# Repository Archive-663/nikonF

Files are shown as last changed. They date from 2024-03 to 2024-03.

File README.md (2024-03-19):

# Lot no. 017 | Nikon F Accessories

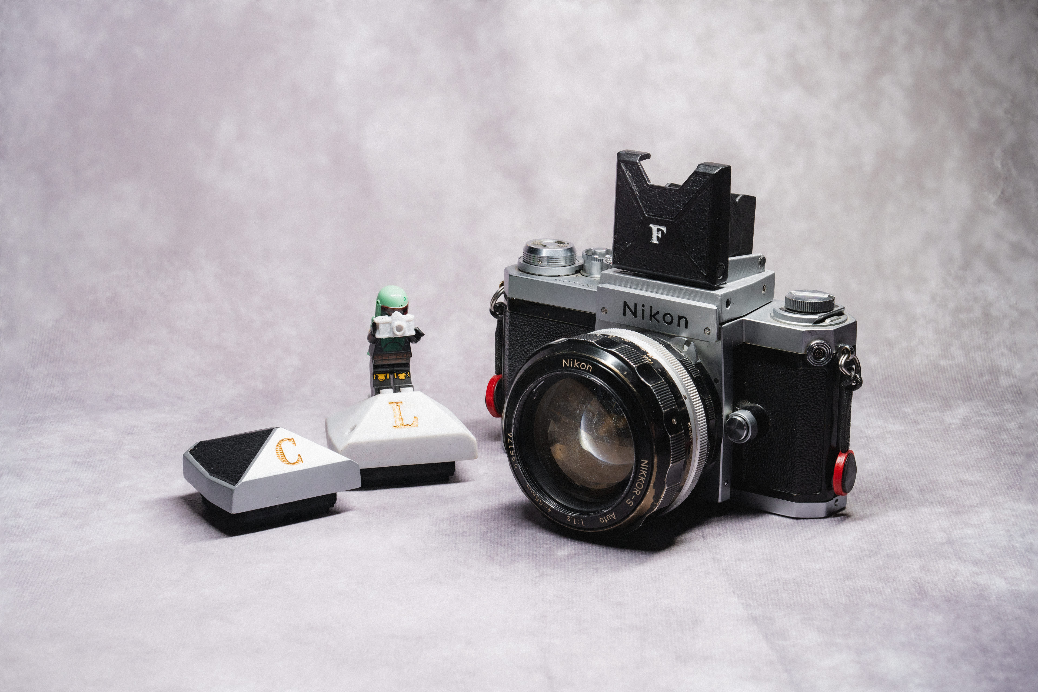
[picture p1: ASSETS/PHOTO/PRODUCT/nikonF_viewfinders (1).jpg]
productPhoto001

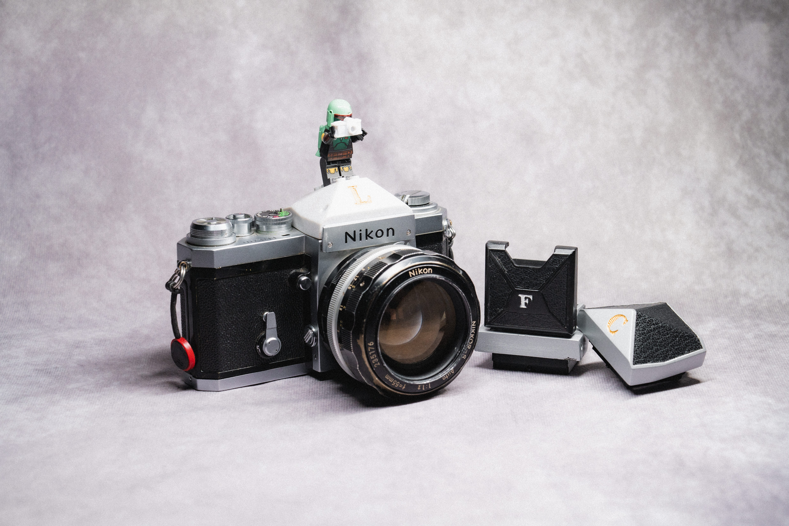
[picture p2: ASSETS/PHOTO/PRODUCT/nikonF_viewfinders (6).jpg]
productPhoto002


### In this repository:
- [Viewfinders](https://github.com/Archive-663/nikonF/tree/main/viewFinders)

### Background Story:
I picked up a Nikon F, FTN finder, and a Nikkor 55mm f1.2 to make a NASA Nikon F. While that particular project is on the backburner, I wanted to shoot the Nikon F with something that wasn't so obtrusively large. I had a broken Canon FTb and figured I could probably use the prism for a DIY viewfinder on my Nikon F. Along with the eye level finder I wanted the cool hipster waist level finder so I could be cool too. For the WLF I picked up the official WLF so I had a point of reference to build on.

There will be more accessories coming down the pipeline like an L-Bracket or Arca-Swiss compatible Grip. 

### Help support Archive 663 with a dontation or monthly sub



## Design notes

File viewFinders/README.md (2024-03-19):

# Lot no. 017 | Nikon F Viewfinders

productPhoto001
productPhoto002

### Features:
- Customizeable Eye Level Finder using whatever spare prism and prism lens you have laying around. Will need CAD software to modify the template to fit your prism combo.
- Simple Waist Level Finder.
- Minimal hardware for assembly.

### In this repository:
- [Eye Level Finder](https://github.com/Archive-663/nikonF/tree/main/viewFinders/eyeLevelFinder)
- [Waist Level Finder](https://github.com/Archive-663/nikonF/tree/main/viewFinders/waistLevelFinder)

### Accompanying video:
<a href='https://youtu.be/oAtRqYk0Bp8' target='_blank'>005 / / the one where i learn to be comfortable in the shadows</a>

### Background Story:
I picked up a Nikon F, FTN finder, and a Nikkor 55mm f1.2 to make a NASA Nikon F. While that particular project is on the backburner, I wanted to shoot the Nikon F with something that wasn't so obtrusively large. I had a broken Canon FTb and figured I could probably use the prism for a DIY viewfinder on my Nikon F. Along with the eye level finder I wanted the cool hipster waist level finder so I could be cool too. For the WLF I picked up the official WLF so I had a point of reference to build on.

The waist level finder was designed with reliability in mind. I tried multiple designs for a compact 3d printed torsion spring but couldn't figure one out with the assembly I had already. I believe having a manual operation for opening and closing the waist level finder will lead to a longer lasting Waist Level Finder. 

### Samples:
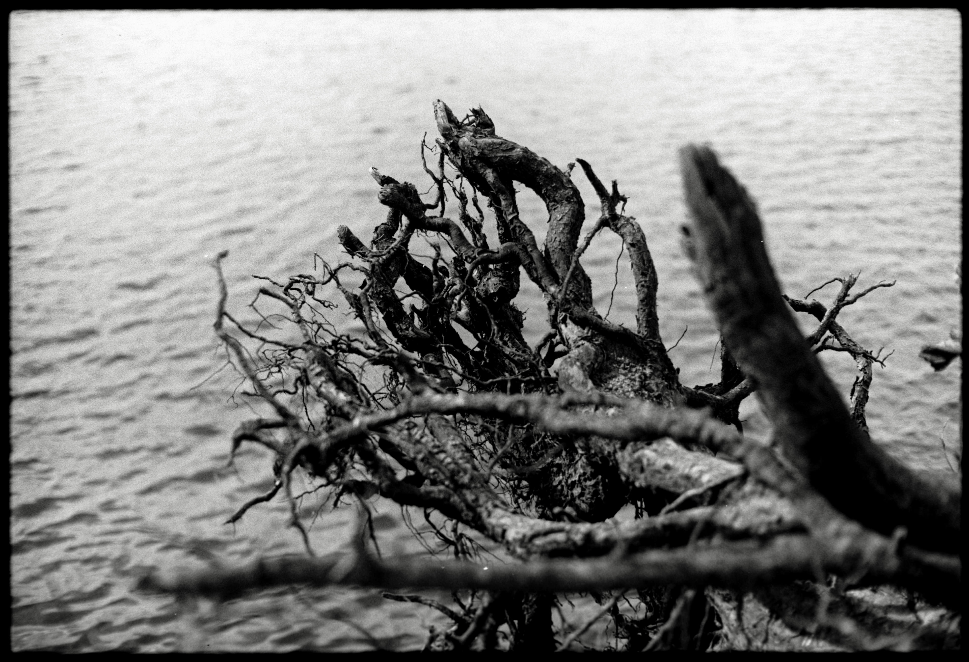
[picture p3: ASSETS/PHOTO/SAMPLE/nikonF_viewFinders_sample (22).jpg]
samplePhoto001

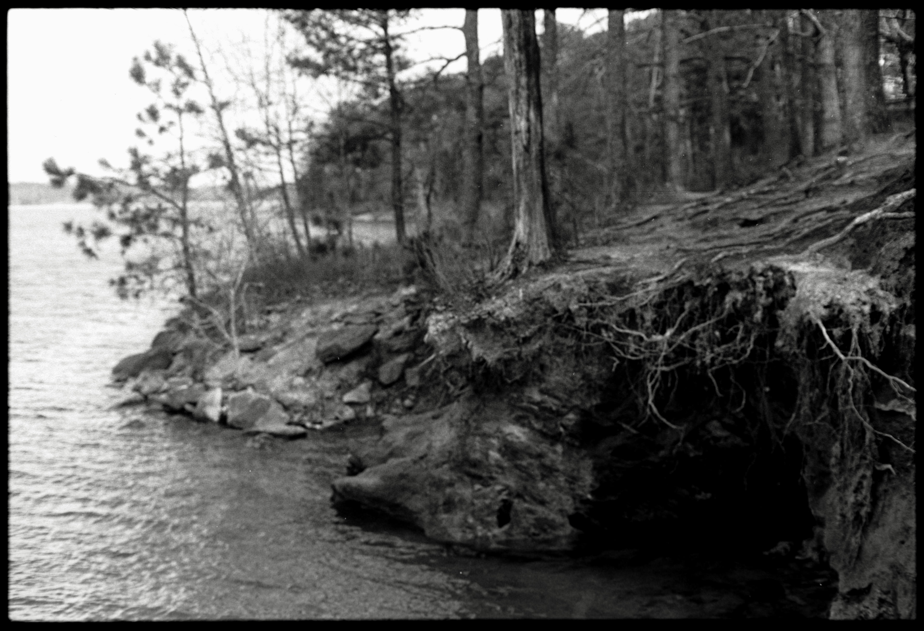
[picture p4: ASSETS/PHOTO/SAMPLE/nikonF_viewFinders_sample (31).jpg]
samplePhoto002

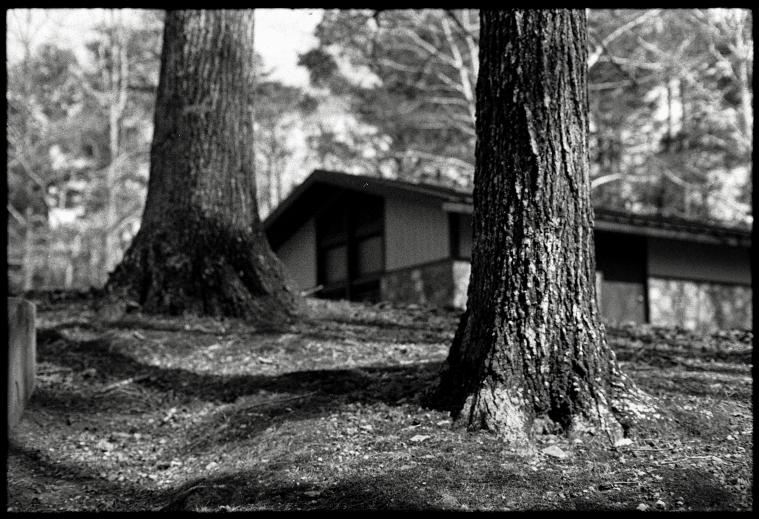
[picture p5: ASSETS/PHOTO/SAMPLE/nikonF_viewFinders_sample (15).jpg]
samplePhoto003

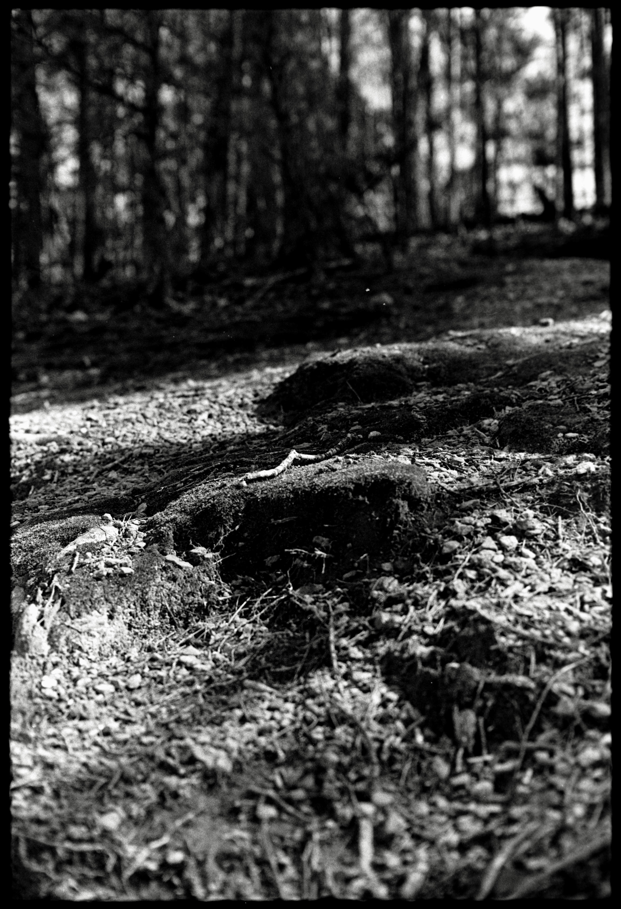
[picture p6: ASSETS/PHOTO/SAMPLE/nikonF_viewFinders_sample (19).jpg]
samplePhoto004

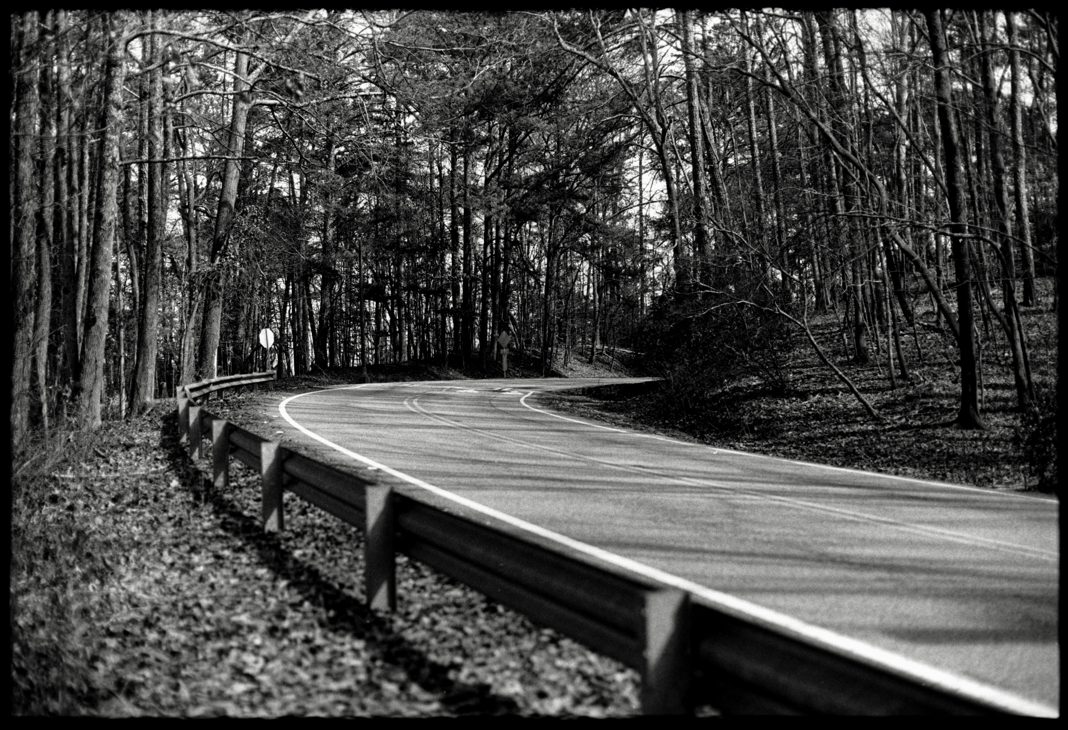
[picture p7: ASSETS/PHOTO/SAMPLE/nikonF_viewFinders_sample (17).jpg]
samplePhoto005

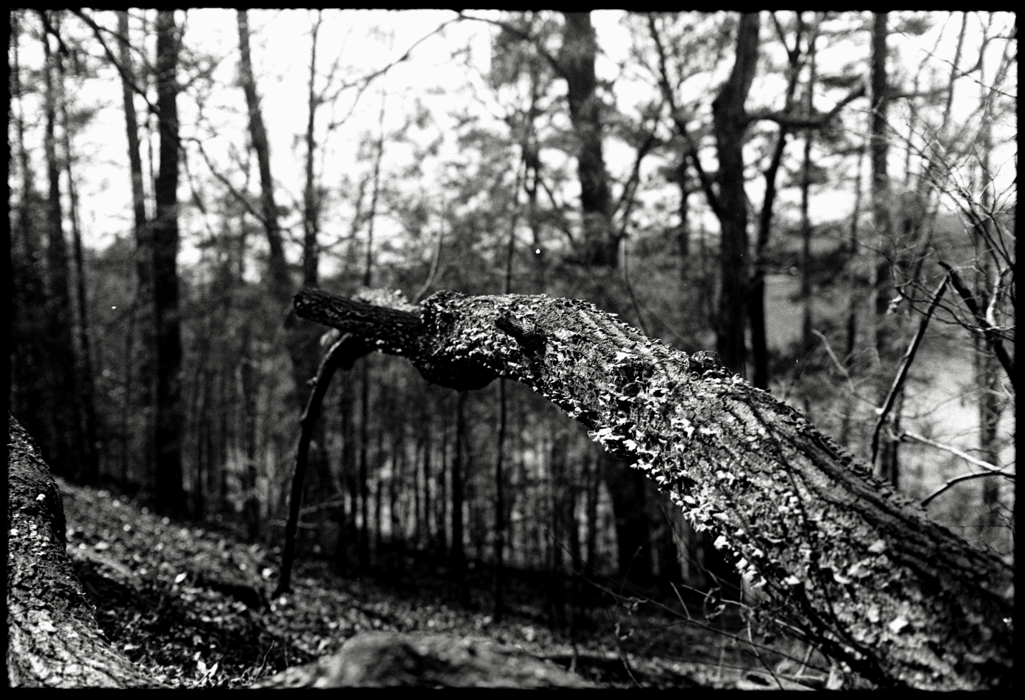
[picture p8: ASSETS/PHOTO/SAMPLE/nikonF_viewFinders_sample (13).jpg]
samplePhoto006


### Help support Archive 663 with a dontation or monthly sub



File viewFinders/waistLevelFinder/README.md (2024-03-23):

# Lot no. 017 | Nikon F Viewfinders - Waist Level Finder

productPhoto001
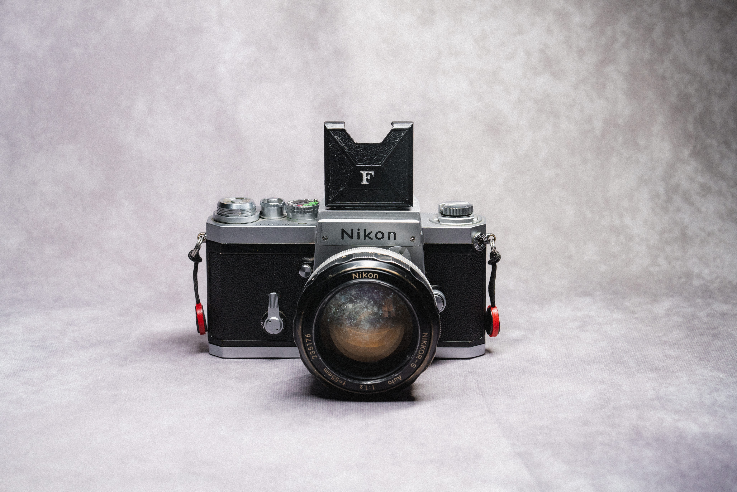
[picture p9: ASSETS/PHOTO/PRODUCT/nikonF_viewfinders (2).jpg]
productPhoto002

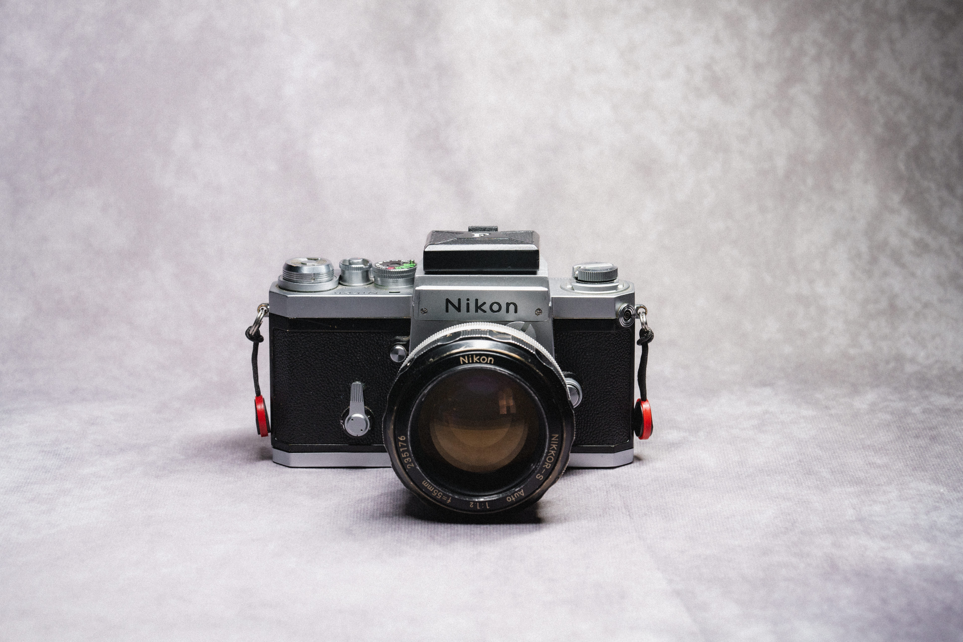
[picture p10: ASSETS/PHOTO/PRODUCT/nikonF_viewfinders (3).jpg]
productPhoto003

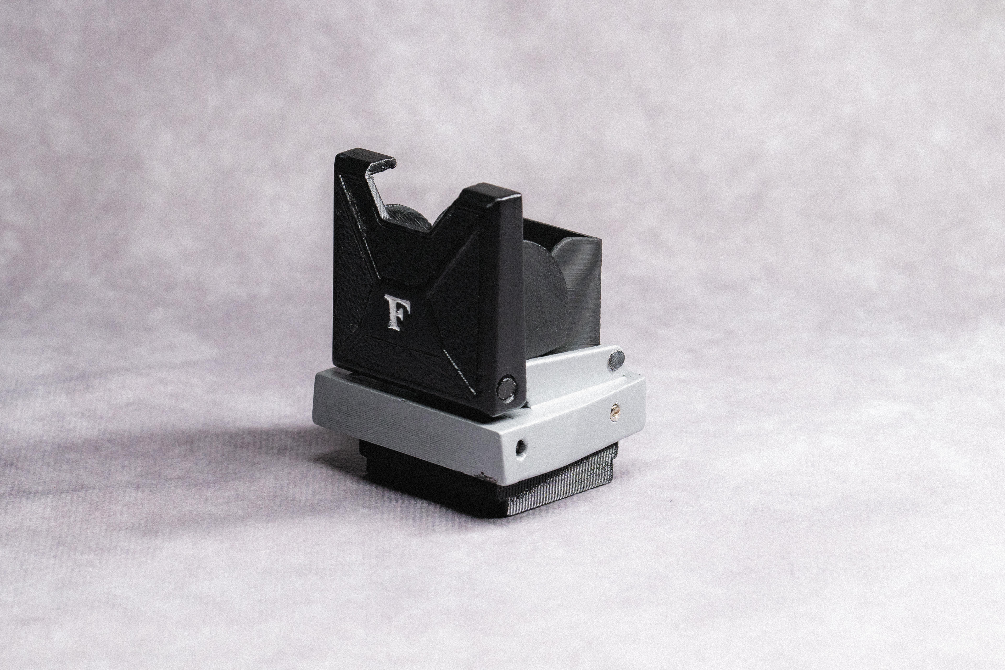
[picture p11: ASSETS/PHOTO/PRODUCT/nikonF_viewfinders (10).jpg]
productPhoto004

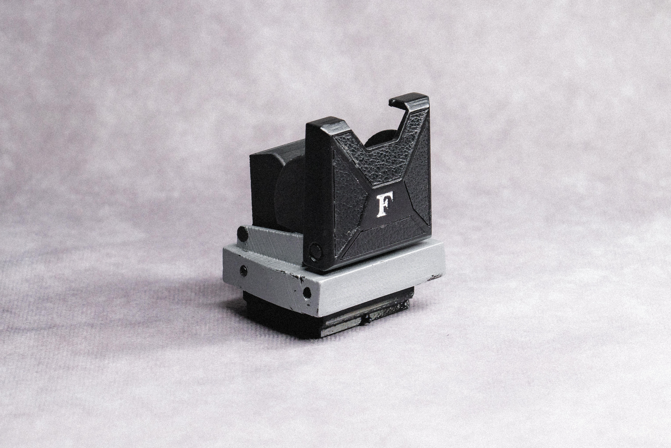
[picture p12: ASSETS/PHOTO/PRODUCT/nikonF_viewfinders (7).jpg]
productPhoto005

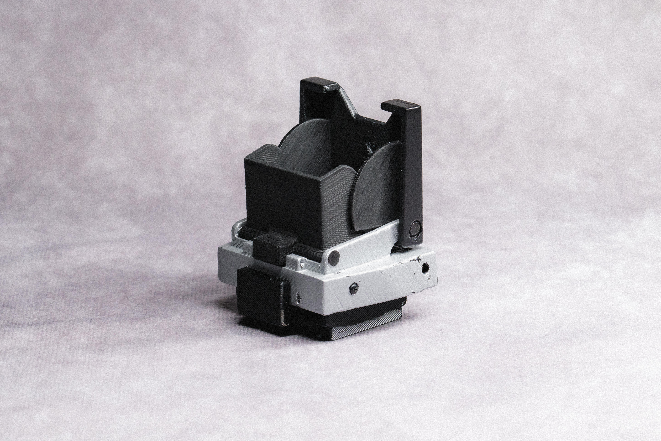
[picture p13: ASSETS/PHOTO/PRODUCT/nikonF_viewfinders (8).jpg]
productPhoto006

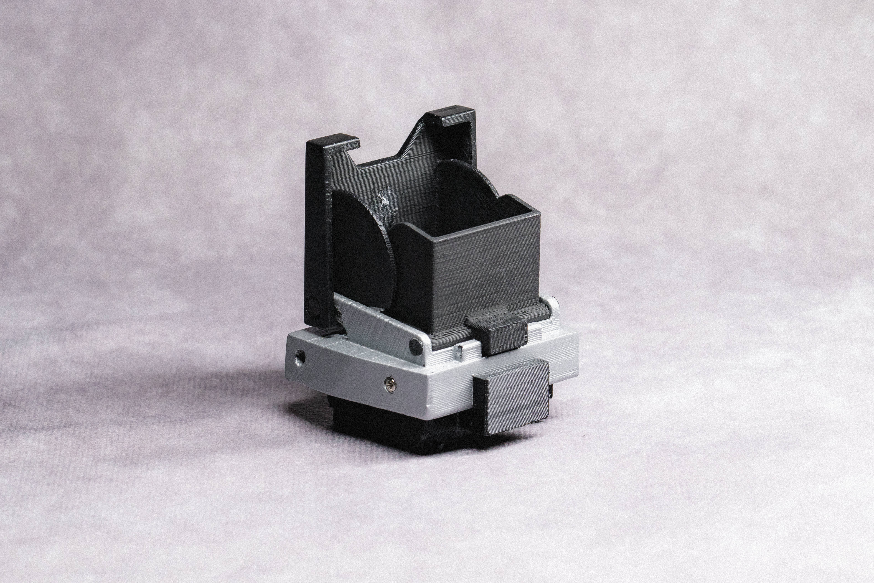
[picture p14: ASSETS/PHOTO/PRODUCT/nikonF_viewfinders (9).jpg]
productPhoto007


### What you'll need:
- 4x M1.6 x 5mm pan head screws (PETG) or self-tappin screws (ABS or PETG)
- 1x M1.6 tap
- 1x 55mm length of 1.75mm filament for upper baffle hinge
- 1x 50mm length of 1.75mm filament for lower baffle hinge
- Sheet of Leatherette

### What would be helpful:
- M1.4 drill bit
- M1.8/M2 drill bit
- Micro files

### Printing help:
Filament recommendation:
- ABS
- PETG

Generally, all my designs have chamfers on the print face of the STL. You can reference the supplied 'printOrientationFile.3mf' files for suggested print orientation.

### Assembly help:
Drill holes to their correct tap size before tapping.
- M1.6 requires M1.4 bore followed by an M1.6 tap.
- M1.8 or M2 bore for screw holes that aren't tapped.
- Bore the hinge holes with an M2 drill bit. Go slowly to keep heat generation down to a minmum. Use water to cool the bit while boring. 
- The hinges are simply lengths of filament with the ends hot riveted down. I use a lighter to set the filament on fire and a bronze punch to hot rivet the end. Do on both sides to lock the hinge in place.
- For the lower baffle you will need to file the hot riveted head down so the upper baffle will close properly. 

Test fit before assembling. Will need to file parts to allow free movement. Depending on your printer you'll have to file down the baffles for them to open and close freely

For the leatherette print the <a href="https://github.com/Archive-663/nikonF/blob/main/ASSETS/TEMPLATES" target='_blank'>leatherette cutting template file</a>. Apply contact cement to both surfaces and adhere the leatherette. 

If you need help opening and closing the waist level finder you can find <a href="https://github.com/Archive-663/nikonF/blob/main/ASSETS/TEMPLATES" target='_blank'>instructions here</a>.

To assemble correctly, please view the _assembly.stp file for help in parts orientation. If you do not have a CAD program, <a href="https://www.freecad.org/downloads.php" target="_blank">download FreeCAD</a> to view the assembly file and better understand how it should assemble. If using FreeCAD, the naming conventions should carry over and you will be able to see which lens element you need from the various smartphone lenses. (Verified in FreeCAD 0.18) If using something like Solid Edge open the file as an assembly to retain the names of the parts.

### Samples:
samplePhoto001
samplePhoto002
samplePhoto003
samplePhoto004
samplePhoto005
samplePhoto006

### Help support Archive 663 with a dontation or monthly sub



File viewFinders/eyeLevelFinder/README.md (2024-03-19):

# Lot no. 017 | Nikon F Viewfinders - Eye Level Finder

productPhoto001
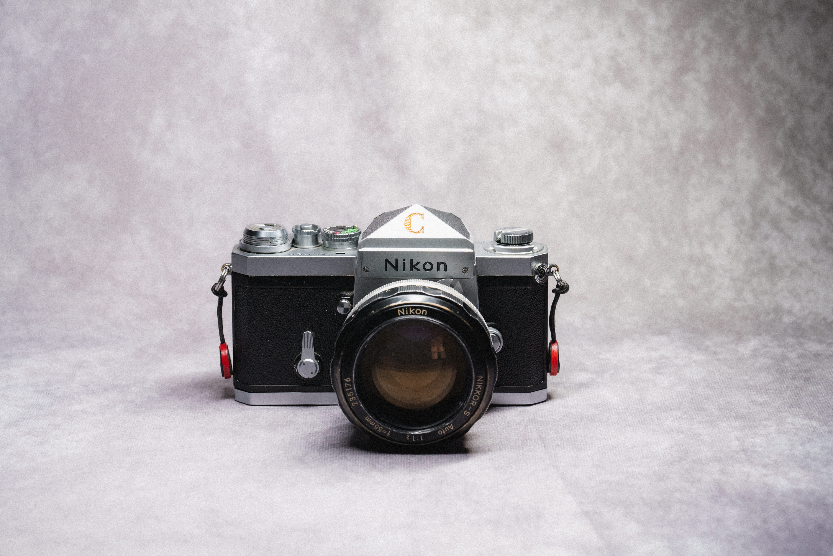
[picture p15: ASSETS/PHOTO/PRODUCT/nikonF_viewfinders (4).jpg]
productPhoto002

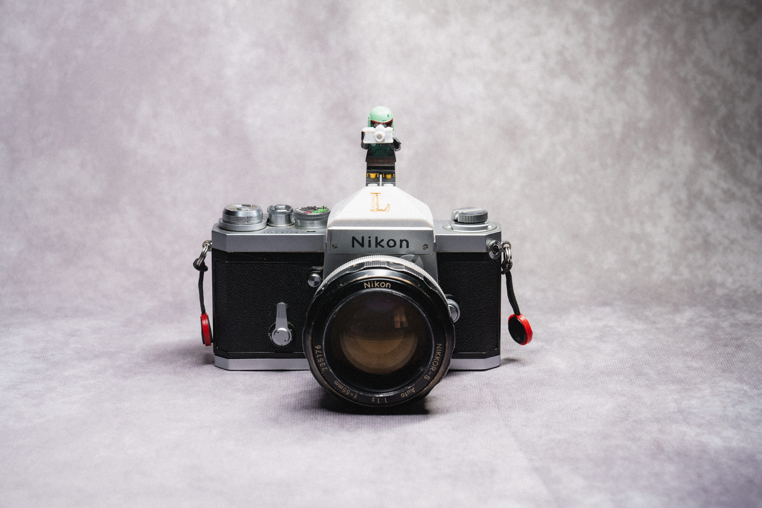
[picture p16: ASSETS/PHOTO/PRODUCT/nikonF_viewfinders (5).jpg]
productPhoto003

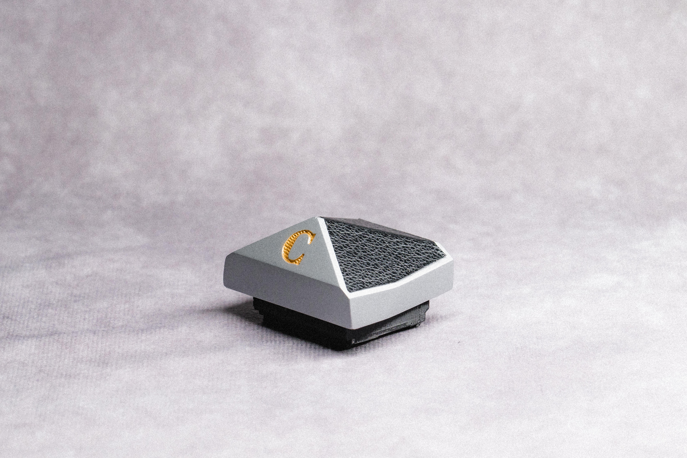
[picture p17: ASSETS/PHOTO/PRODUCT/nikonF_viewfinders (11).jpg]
productPhoto004

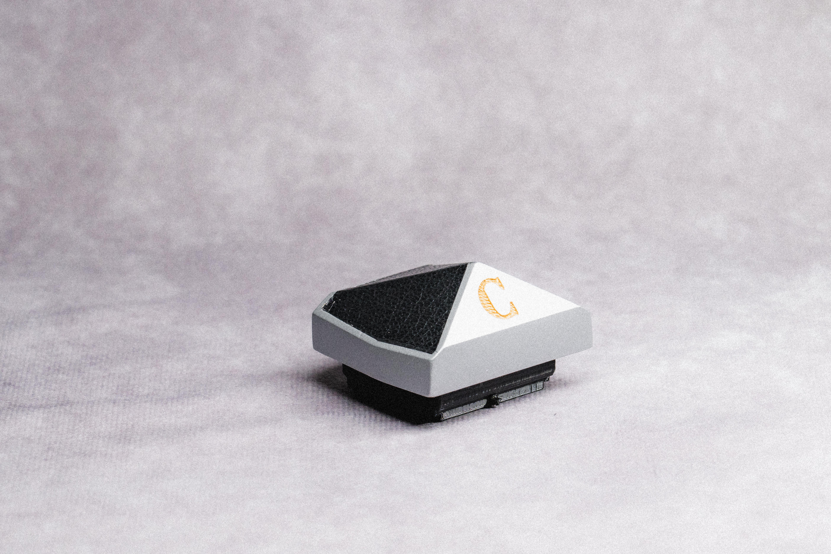
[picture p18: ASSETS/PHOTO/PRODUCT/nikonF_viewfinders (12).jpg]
productPhoto005

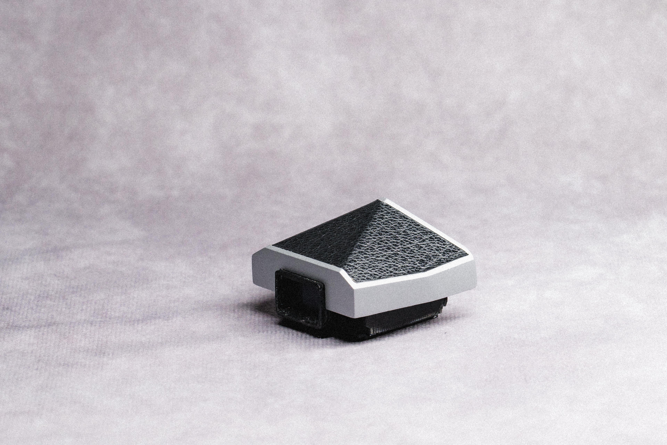
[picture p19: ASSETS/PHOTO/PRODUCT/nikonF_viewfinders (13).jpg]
productPhoto006

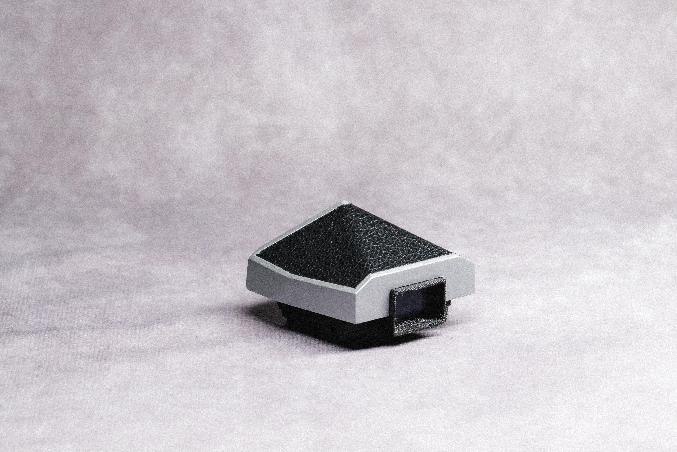
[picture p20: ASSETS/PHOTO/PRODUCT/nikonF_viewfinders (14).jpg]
productPhoto007

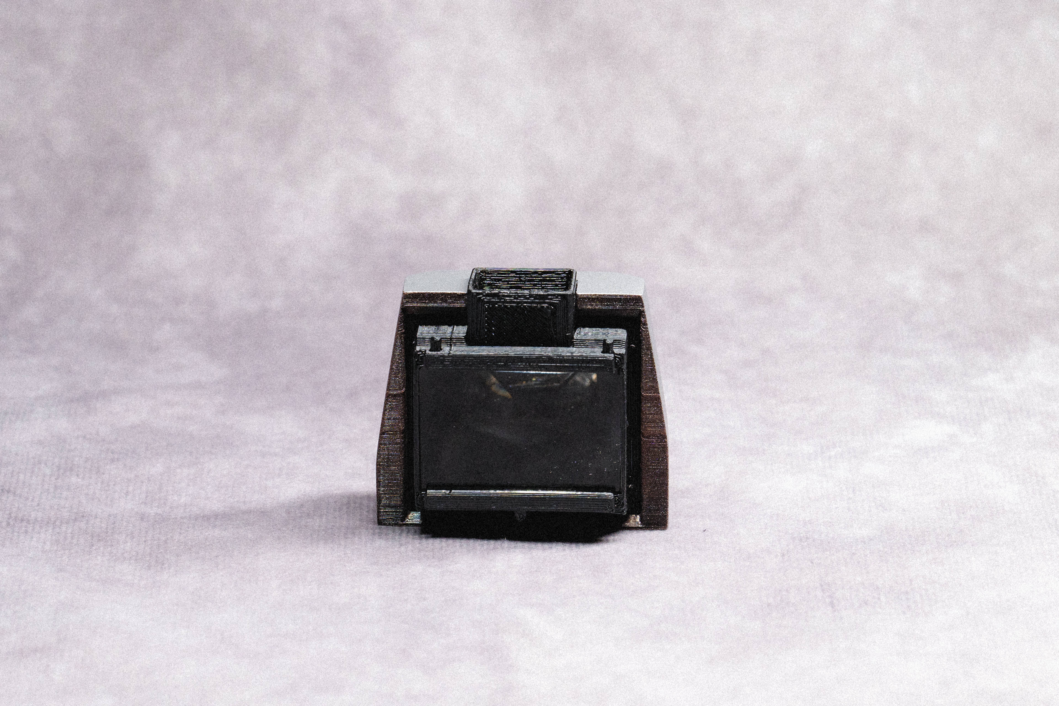
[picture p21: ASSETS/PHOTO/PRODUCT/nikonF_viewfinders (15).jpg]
productPhoto008


### What you'll need:
- 4x M1.6 x 5mm pan head screws (PETG) or self-tappin screws (ABS or PETG)
- 1x M1.6 tap
- 1x Canon FTb Prism
- 1x Canon FTb Prism Lens
  or
- 1x Prism from an SLR
- 1x Prism Lens from an SLR
- Sheet of Leatherette

### What would be helpful:
- M1.4 drill bit
- M1.8/M2 drill bit
- Micro files

### Notes:
I've included a template file so you can adjust or build your own viewfinder using a compatible prism. Additionally, there is a Lego FTB top that you can use to add some character with Legos. 

### Printing help:
Filament recommendation:
- ABS
- PETG

Generally, all my designs have chamfers on the print face of the STL. You can reference the supplied 'printOrientationFile.3mf' files for suggested print orientation.

### Assembly help:
Drill holes to their correct tap size before tapping.
- M1.6 requires M1.4 bore followed by an M1.6 tap.
- M1.8 or M2 bore for screw holes that aren't tapped.
- You'll want to handle the prism from the Canon FTB with care. Use gloves to handle to limit exposure to your body's natural oils.

Test fit before assembling. Will need to file parts to allow free movement. Depending on your printer you'll have to file down the baffles for them to open and close freely

For the leatherette print the <a href="https://github.com/Archive-663/nikonF/blob/main/ASSETS/TEMPLATES" target='_blank'>leatherette cutting template file</a>. Apply contact cement to both surfaces and adhere the leatherette. 

To assemble correctly, please view the _assembly.stp file for help in parts orientation. If you do not have a CAD program, <a href="https://www.freecad.org/downloads.php" target="_blank">download FreeCAD</a> to view the assembly file and better understand how it should assemble. If using FreeCAD, the naming conventions should carry over and you will be able to see which lens element you need from the various smartphone lenses. (Verified in FreeCAD 0.18) If using something like Solid Edge open the file as an assembly to retain the names of the parts.

### Samples:
samplePhoto001
samplePhoto002
samplePhoto003
samplePhoto004
samplePhoto005
samplePhoto006

### Help support Archive 663 with a dontation or monthly sub



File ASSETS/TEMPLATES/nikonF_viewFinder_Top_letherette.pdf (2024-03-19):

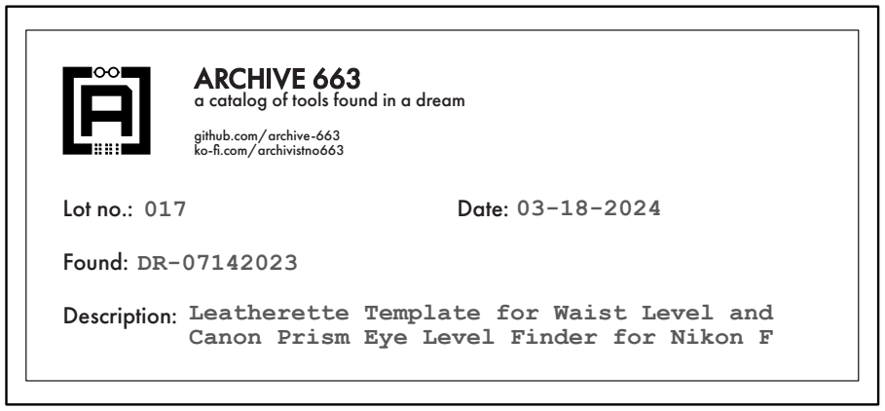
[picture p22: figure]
Lot no.:; Date:; Found:; Description:; ARCHIVE 663 a catalog of tools found in a dream; github.com/archive-663 ko-fi.com/archivistno663

Leatherette Template for Waist Level and Canon Prism Eye Level Finder for Nikon F

### Waist Level Finder

1"

### Canon Prism Eye Level Finder

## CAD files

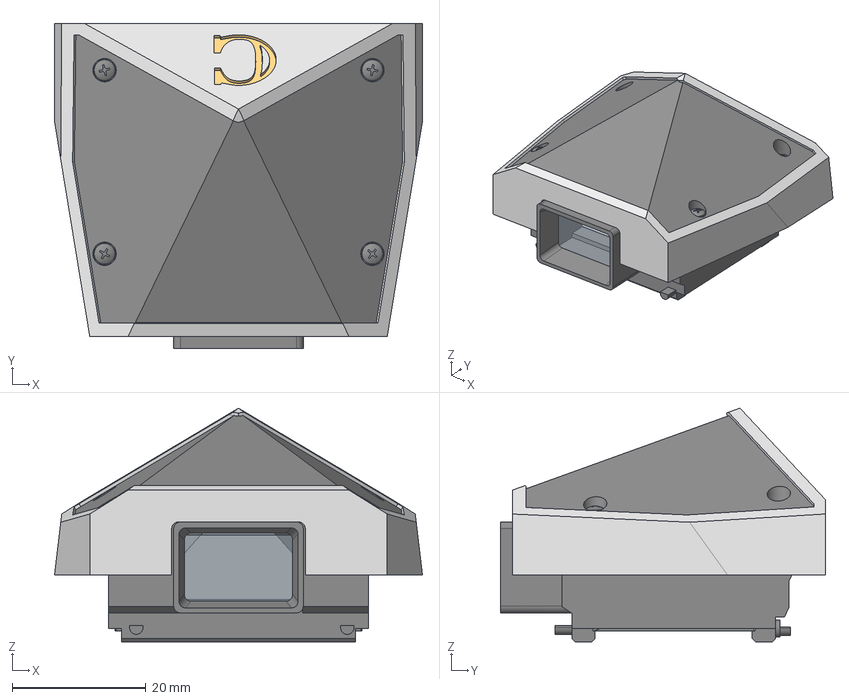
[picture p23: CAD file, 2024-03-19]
viewFinders/eyeLevelFinder/canonFTB_prism/STEP/nikonF_viewFinder_canonFTB_assembly.stp
55.1 x 48.7 x 35.0 mm
nikonF_viewFinder_canonFTBBottom
nikonF_viewFinder_canonFTBTop_STD
M1.6_panHead_5mm x 4
nikonF_prismEye_canonFTB
nikonF_prism_canonFTB

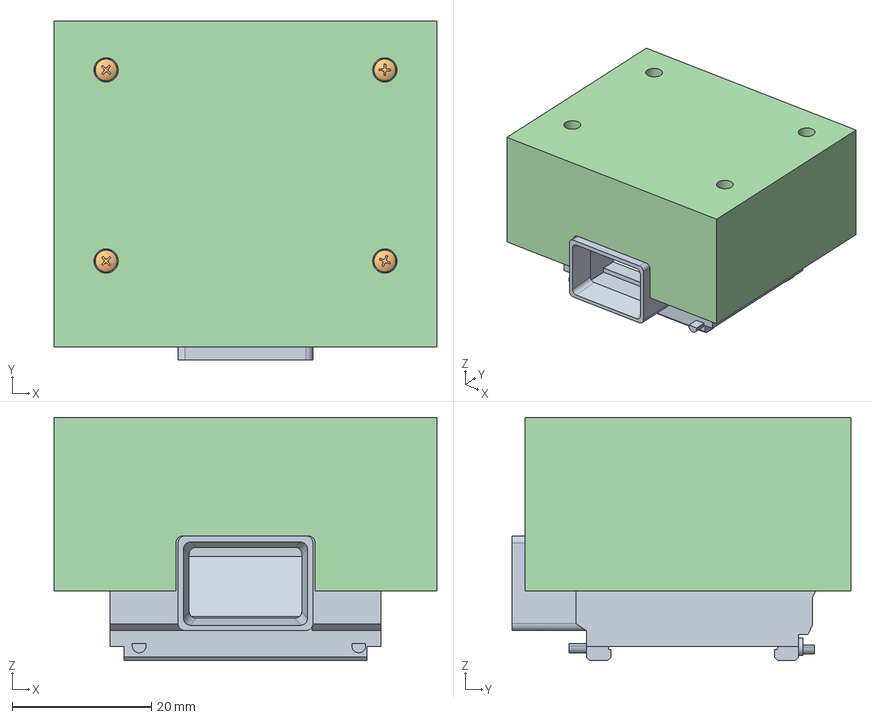
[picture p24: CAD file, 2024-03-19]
viewFinders/eyeLevelFinder/template/STEP/nikonF_viewFinder_template_assembly.stp
55.1 x 48.7 x 35.0 mm
nikonF_viewFinder_baseBottom_Template
M1.6_panHead_5mm x 4
nikonF_viewFinder_baseTop_Template

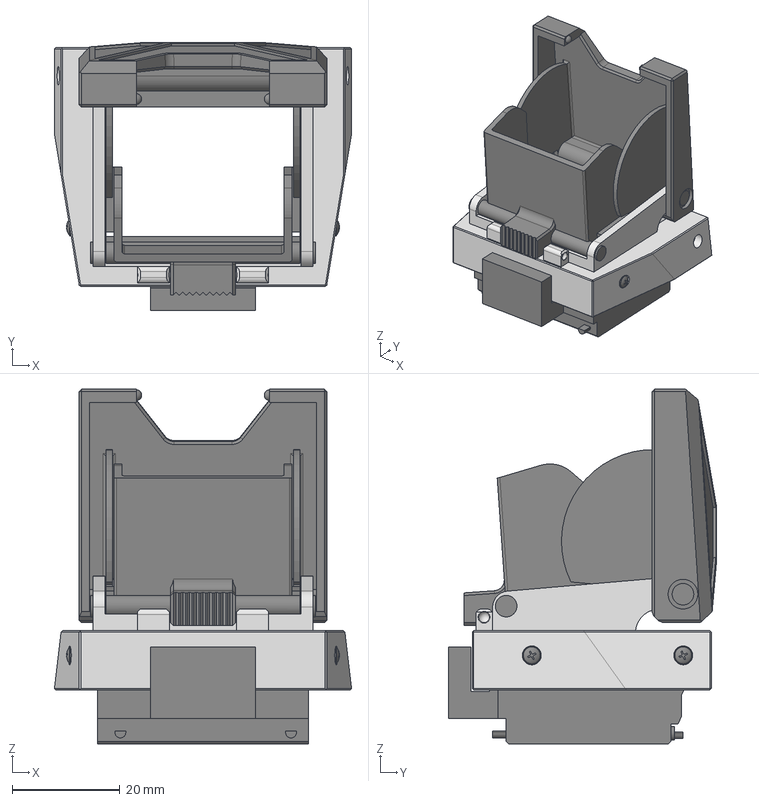
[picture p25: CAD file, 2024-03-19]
viewFinders/waistLevelFinder/STEP/nikonF_waistLevelFinder_assembly.stp
55.0 x 49.7 x 65.7 mm
nikonF_waistLevelFinder_Bottom
nikonF_waistLevelFinder_Top
M1.6_panHead_5mm x 4
nikonF_waistLevelFinder_Top_upperBaffle
nikonF_waistLevelFinder_Top_lowerBaffle
nikonF_waistLevelFinder_Top_upperBaffle_hingePin_capped
nikonF_waistLevelFinder_Top_lowerBaffle_hingePin_capped

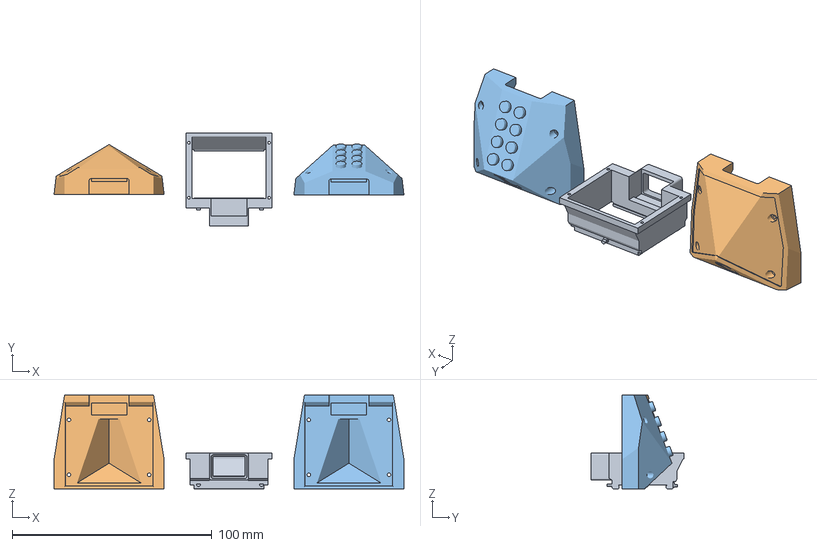
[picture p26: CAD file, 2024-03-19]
viewFinders/eyeLevelFinder/canonFTB_prism/STL/nikonF_viewFinder_canonFTB_printOrientationFile.3mf
175.1 x 46.7 x 46.9 mm
nikonF_viewFinder_canonFTBBottom.stl
nikonF_viewFinder_canonFTBTop_STD.stl
nikonF_viewFinder_canonFTBTop_lego.stl

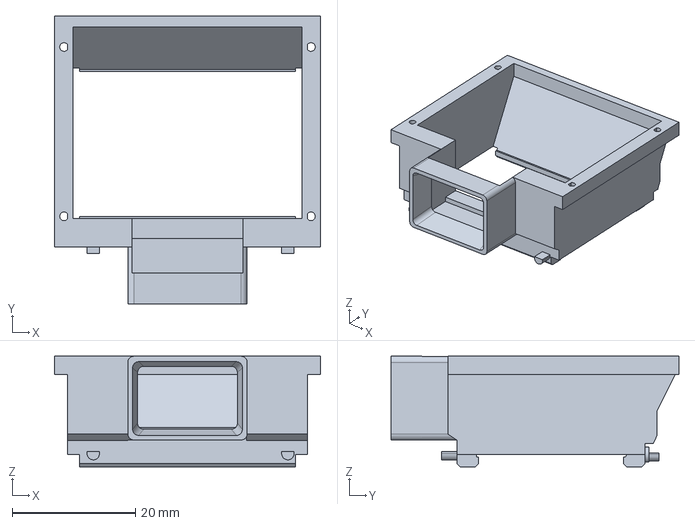
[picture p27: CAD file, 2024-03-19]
viewFinders/eyeLevelFinder/template/STEP/nikonF_viewFinder_baseBottom_Template.stp
43.2 x 46.7 x 17.9 mm

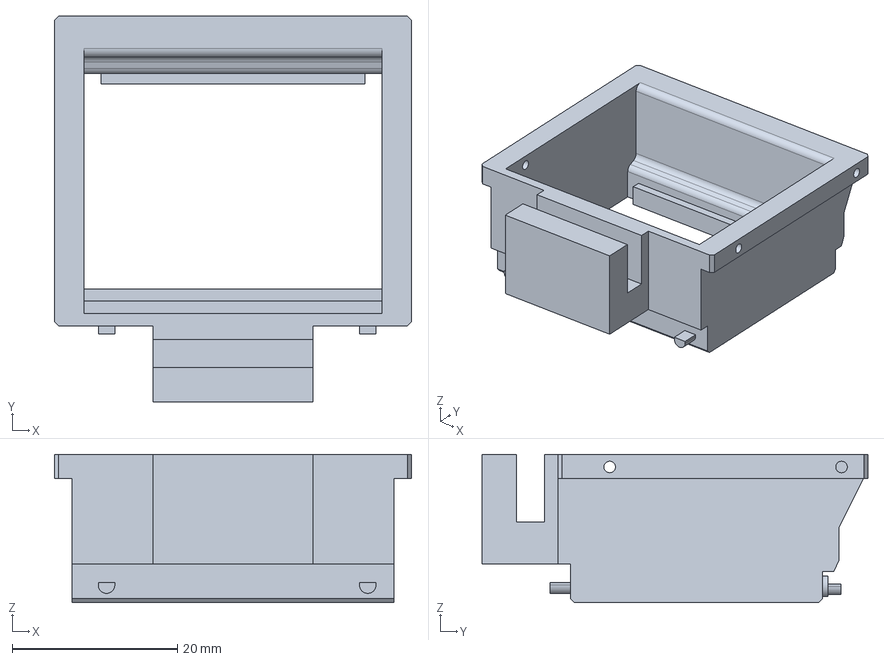
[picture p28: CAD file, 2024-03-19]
viewFinders/waistLevelFinder/STEP/nikonF_waistLevelFinder_Bottom.stp
43.2 x 46.7 x 17.9 mm

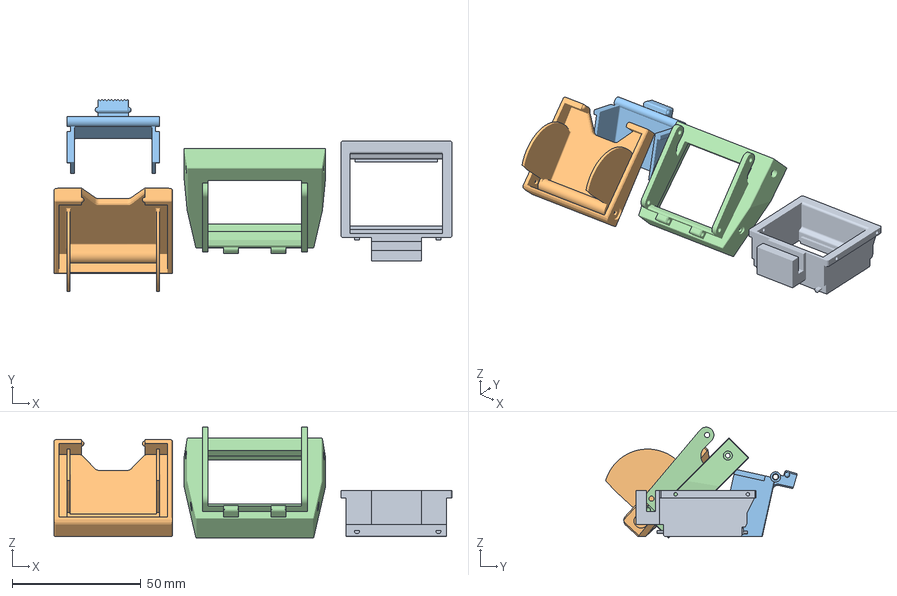
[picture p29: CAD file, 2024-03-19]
viewFinders/waistLevelFinder/STL/nikonF_waistLevelFinder_printOrientationFile.3mf
154.6 x 74.5 x 43.0 mm
nikonF_waistLevelFinder_Bottom.stl
nikonF_waistLevelFinder_Top_upperBaffle.stl
nikonF_waistLevelFinder_Top_lowerBaffle.stl
nikonF_waistLevelFinder_Top.stl

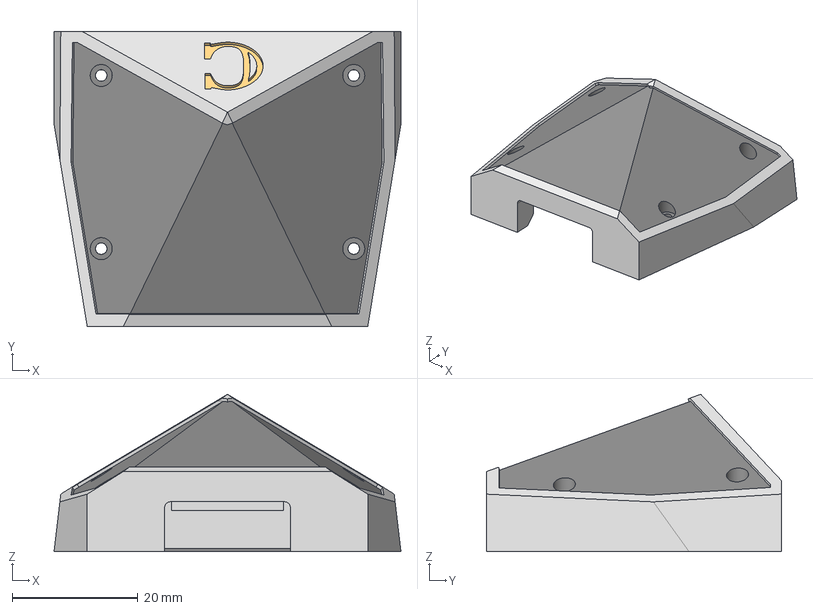
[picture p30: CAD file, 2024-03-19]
viewFinders/eyeLevelFinder/canonFTB_prism/STEP/nikonF_viewFinder_canonFTBTop_STD.stp
55.1 x 46.9 x 25.0 mm

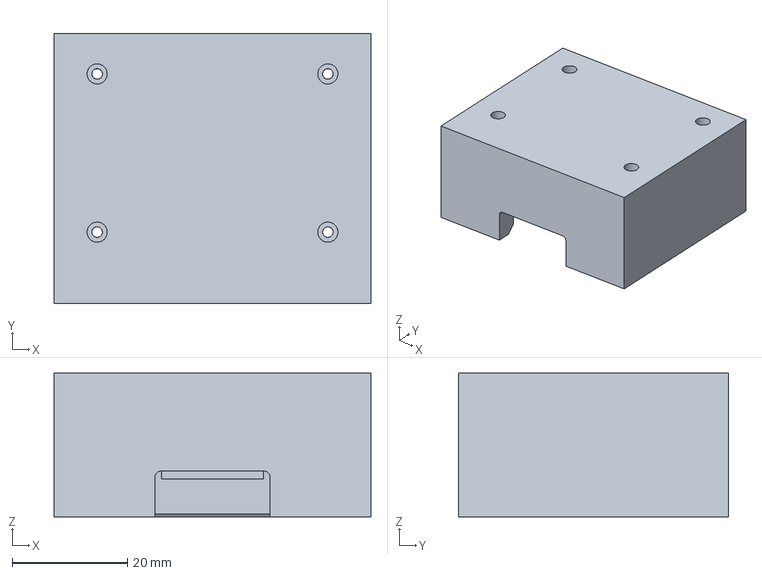
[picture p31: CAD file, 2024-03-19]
viewFinders/eyeLevelFinder/template/STEP/nikonF_viewFinder_baseTop_Template.stp
55.1 x 46.9 x 25.0 mm

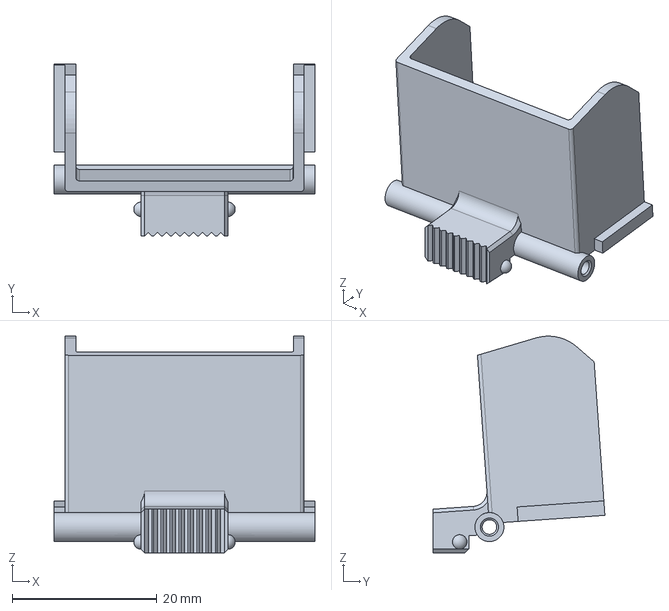
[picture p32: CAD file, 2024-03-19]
viewFinders/waistLevelFinder/STEP/nikonF_waistLevelFinder_Top_lowerBaffle.stp
36.0 x 23.7 x 29.9 mm

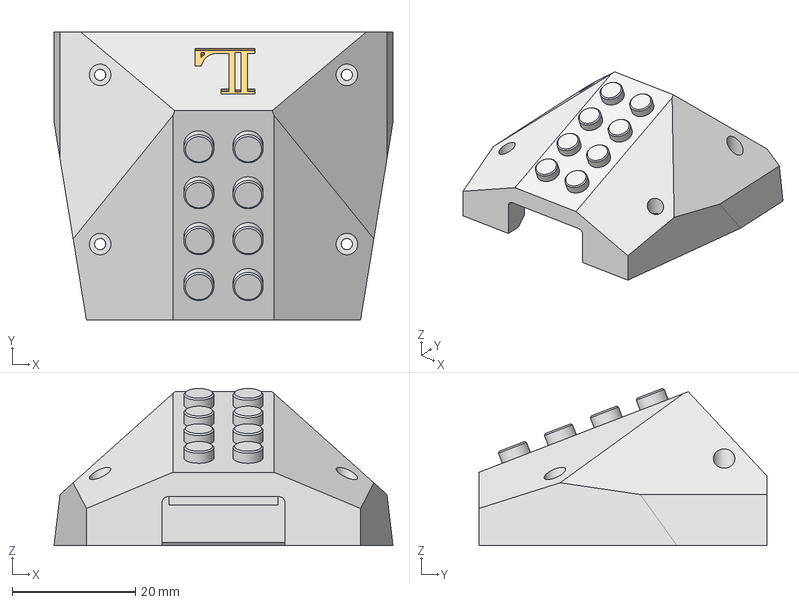
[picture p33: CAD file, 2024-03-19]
viewFinders/eyeLevelFinder/canonFTB_prism/STEP/nikonF_viewFinder_canonFTBTop_lego.stp
55.1 x 46.9 x 25.5 mm

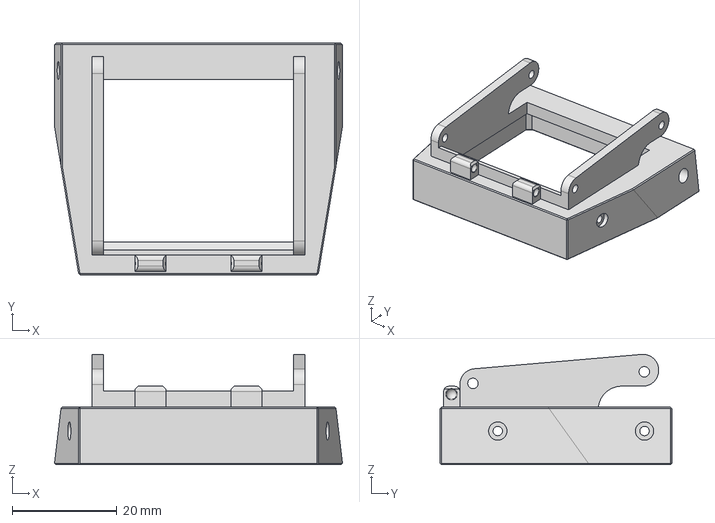
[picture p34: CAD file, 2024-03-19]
viewFinders/waistLevelFinder/STEP/nikonF_waistLevelFinder_Top.stp
55.0 x 44.3 x 21.1 mm

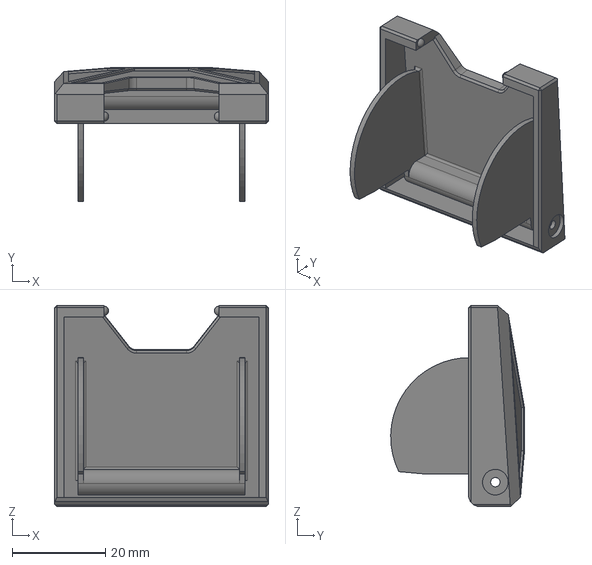
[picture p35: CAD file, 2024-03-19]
viewFinders/waistLevelFinder/STEP/nikonF_waistLevelFinder_Top_upperBaffle.stp
46.0 x 28.7 x 43.3 mm

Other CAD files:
viewFinders/eyeLevelFinder/canonFTB_prism/STEP/nikonF_viewFinder_canonFTBBottom.stp
viewFinders/eyeLevelFinder/canonFTB_prism/STL/nikonF_viewFinder_canonFTBBottom.stl
viewFinders/eyeLevelFinder/canonFTB_prism/STL/nikonF_viewFinder_canonFTBTop_STD.stl
viewFinders/eyeLevelFinder/canonFTB_prism/STL/nikonF_viewFinder_canonFTBTop_lego.stl
viewFinders/eyeLevelFinder/template/STL/nikonF_viewFinder_baseBottom_Template.stl
viewFinders/eyeLevelFinder/template/STL/nikonF_viewFinder_baseTop_Template.stl
viewFinders/waistLevelFinder/STL/nikonF_waistLevelFinder_Bottom.stl
viewFinders/waistLevelFinder/STL/nikonF_waistLevelFinder_Top.stl
viewFinders/waistLevelFinder/STL/nikonF_waistLevelFinder_Top_lowerBaffle.stl
viewFinders/waistLevelFinder/STL/nikonF_waistLevelFinder_Top_upperBaffle.stl

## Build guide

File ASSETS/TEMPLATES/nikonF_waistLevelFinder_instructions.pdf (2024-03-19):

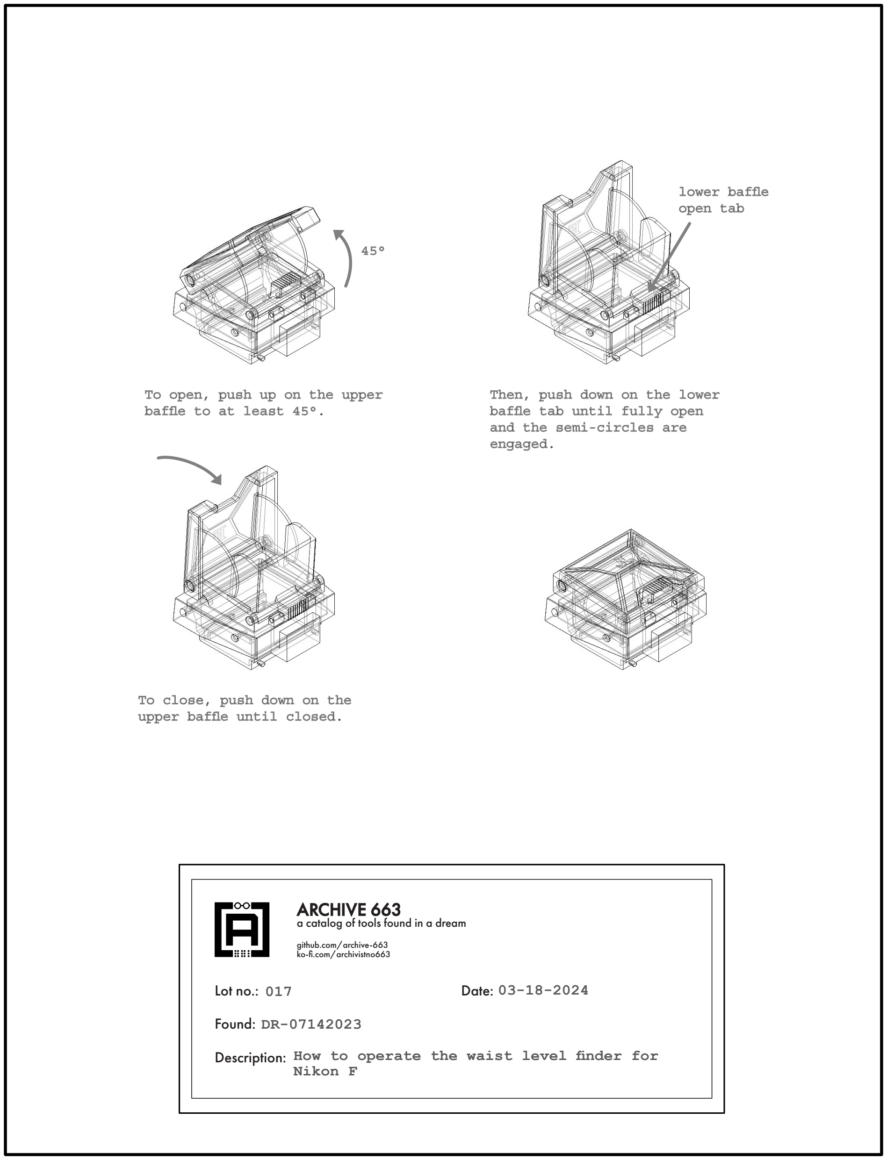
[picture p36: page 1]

To open, push up on the upper baffle to at least 45°.

To close, push down on the upper baffle until closed.

Then, push down on the lower baffle tab until fully open and the semi-circles are
engaged.

lower baffle
open tab

45°

Lot no.: | Date:
Found: Description: | 017 03-18-2024

## ARCHIVE 663

| a catalog of tools found in a dream

How to operate the waist level finder for Nikon F

DR-07142023

github.com/archive-663
ko-fi.com/archivistno663

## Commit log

2024-03-19 Archive Lot no. 017
    Uploading Nikon F SLR accessories
    [nikonF_viewFinder_baseBottom_Template.stl, nikonF_viewFinder_baseBottom_Template.stp, nikonF_viewFinder_baseTop_Template.stl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]
2024-03-19 Updated Step Files
    [nikonF_viewFinder_baseBottom_Template.stp, nikonF_viewFinder_baseTop_Template.stp, nikonF_viewFinder_canonFTBBottom.stp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]
